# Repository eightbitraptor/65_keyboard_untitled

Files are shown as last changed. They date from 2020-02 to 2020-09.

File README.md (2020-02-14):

# 65_keyboard_untitled

My as yet unnamed 65% keyboard design

## Project structure

- [`layouts`](layouts/) - contains all the layout options I explored and the related artifacts. Generated using [Keyboard Layout Editor](https://www.keyboard-layout-editor.com)

## Layout

**tl;dr - pretty standard 65% layout WKL bottom row and split backspace**

This keyboard is a 65% board. Which means it's basically a 60% layout that's been extended by 1 column which allows us to comfortably incorporate an arrow cluster and a couple of the useful navigation keys. It's a fixed layout because it's being built just for me as a personal project. So don't expect any allowances in plate or case design for other layouts.

It's using a HHKB style layout (ANSI base with split backspace, Esc next to the 1), a Winkeyless style bottom row with a 7u spacebar, and a 1u logo blocker in the top right (because aesthetics). The right shift has been shrunk to 1.75u to allow for the up arrow. It looks like this:

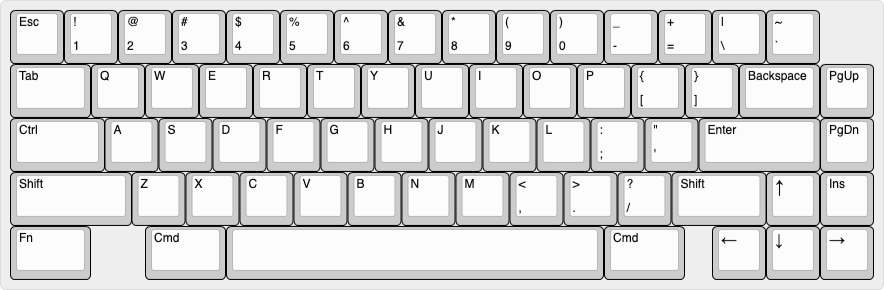
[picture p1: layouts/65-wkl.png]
65% WKL Layout


## Process

1. Decide on your layout using KLE. don't forget to either download the JSON or save your layout to Github. NOTE: To make the process easier later. I'm using the Tsangan layout to generate the platefile dxf. Tsangan is the same as WKL but with a 1u key instead of a blocker on the left side modifiers. I'm generating it this way as it makes the top case easier to design as it gives me the markings for the key that I can use as anchors in my cad program to situate the blocker.
2. copy the raw data from KLE into Swillkb. Choose cutout type and stab type - I chose simple square switch cutouts and combined cherry/co-star stab cutouts - I'm going to make the stab cutouts bigger later anyway as I want to use PCB mounted stabs.
3. Get Fusion 360 and follow along Quantriks case video, it's really good. I think I probably re-did my case 2 or three times as I understood more about Fusion in each step of the process. Also modify the design. I made the bottom/weight different as I didn't like the design in the video that much and I changed up the screw positioning and plate mounting stuff a bit. NOTE: There's no USB cutout at this point, I haven't decided where I want it yet, and there's no PCB
4. Design a PCB Schematic in KiCad. I followed along with MrKeebs videos and cross references against avrforums and some other places on the internet to verify my design. Some caveats
  - I'm using ai03's keyboard switch symbol and footprint library. I really wanted to just use the built in KiCad footprints but they don't come with a 7u spacebar, which mine is (and also has flipped stabilizers)
  - I chose the matrix layout based on the connection diagram from the kbfirmwarebuilder. I don't really know how to design a matrix other than to keep the connections as short as possible, so I went with the path of least resistance (badum tish)

## Obligatory Potato Renders

My Thinkpad struggled hard with these...

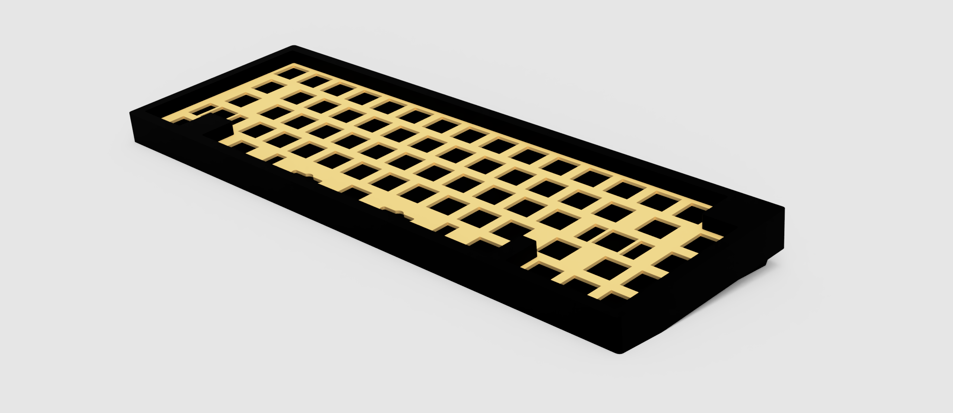
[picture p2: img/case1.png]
case 1

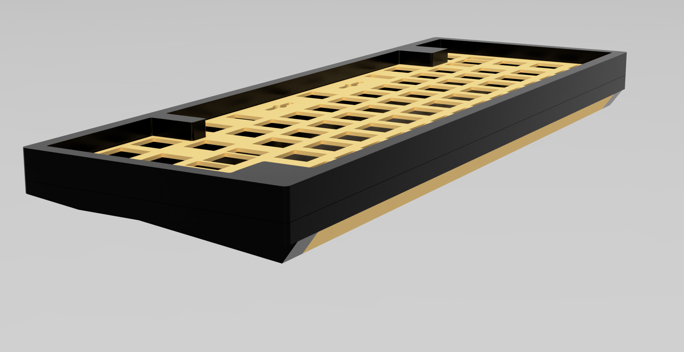
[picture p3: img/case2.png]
case 2


## KBFirmware Matrix map

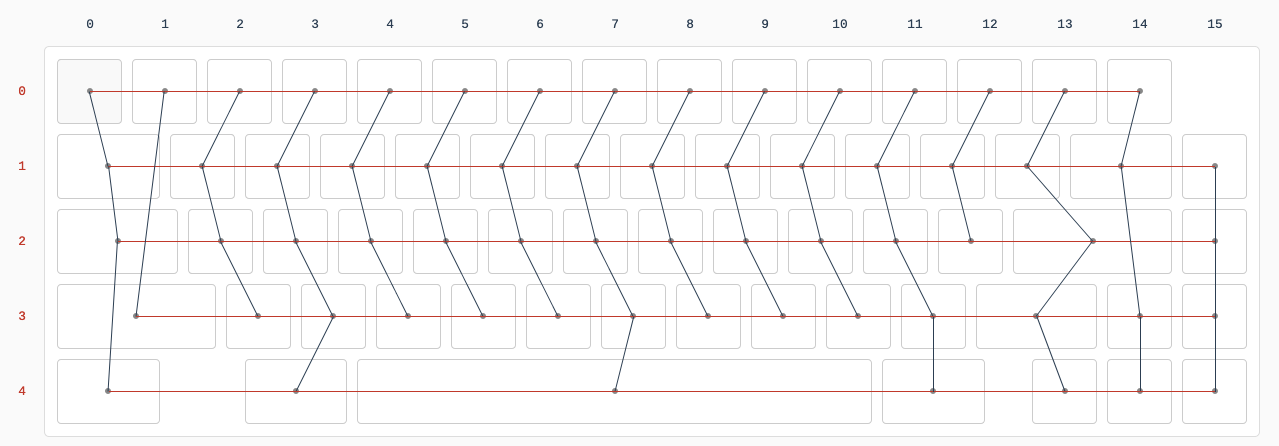
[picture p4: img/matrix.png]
wiremap


## Resources

### Videos/reading material

- Quantrik's 65% Keyboad Case design with Fusion 360 stream
  -  https://www.youtube.com/watch?v=4P0zfLLblOw
- Mr Keebs and Gondolindri's PCB design stream series
  - https://www.youtube.com/watch?v=Nk0egpDFqRA
  - https://www.youtube.com/watch?v=beyh0__tf5M
  - https://www.youtube.com/watch?v=pllksuZwJL0

### Tools

- Keyboard Layout Editor
  - http://www.keyboard-layout-editor.com/
- Swillkb's Plate CAD builder
  - http://builder.swillkb.com/
- MrKeebs PCB Layout Creator
  - http://kbpcb.mrkeebs.com/
- Keyboard Firmware Builder
  - https://kbfirmware.com

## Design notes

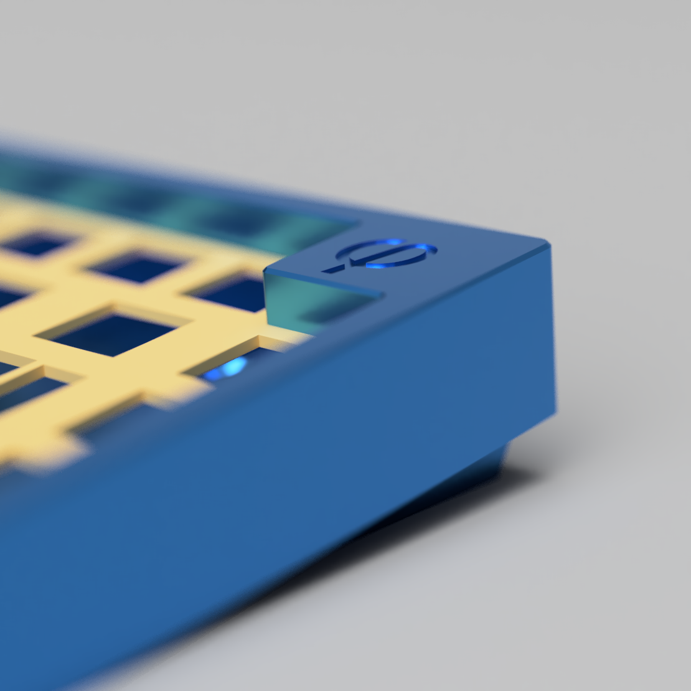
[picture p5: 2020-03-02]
Renders/design_2020-Feb-27_09-39-12AM-000_CustomizedView2532959662.png

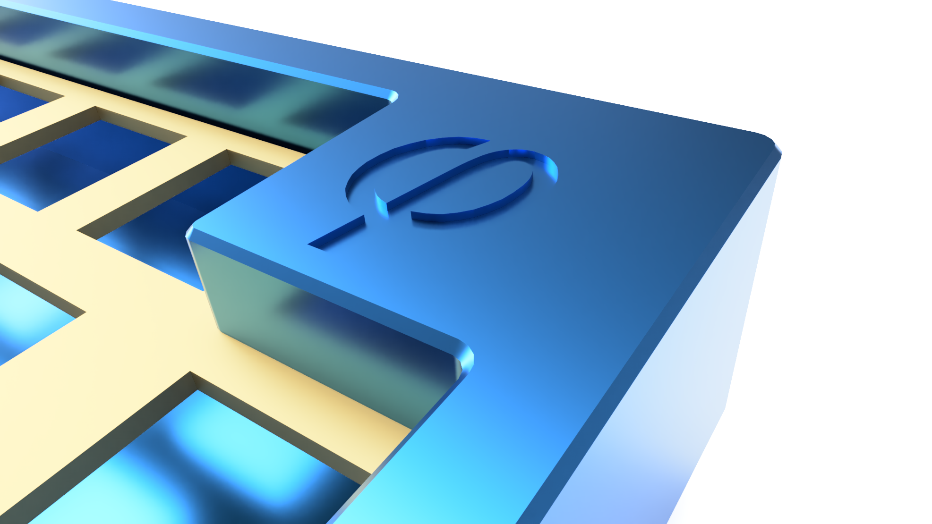
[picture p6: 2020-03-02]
Renders/design_2020-Feb-27_09-46-24AM-000_CustomizedView17708917623.png

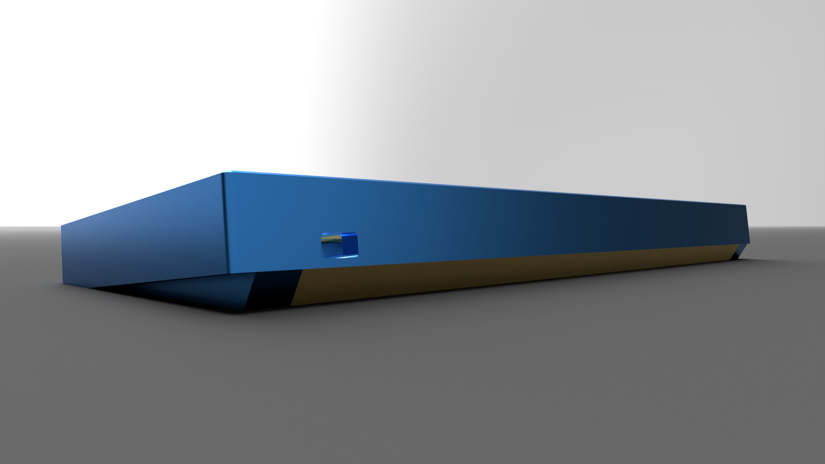
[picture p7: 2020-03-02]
Renders/design_2020-Feb-27_09-48-49AM-000_CustomizedView24021075067.png

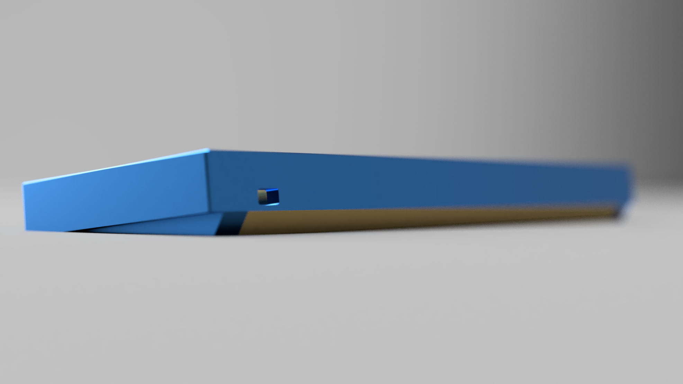
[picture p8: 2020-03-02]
Renders/design_2020-Feb-27_09-40-59AM-000_CustomizedView21154432253.png

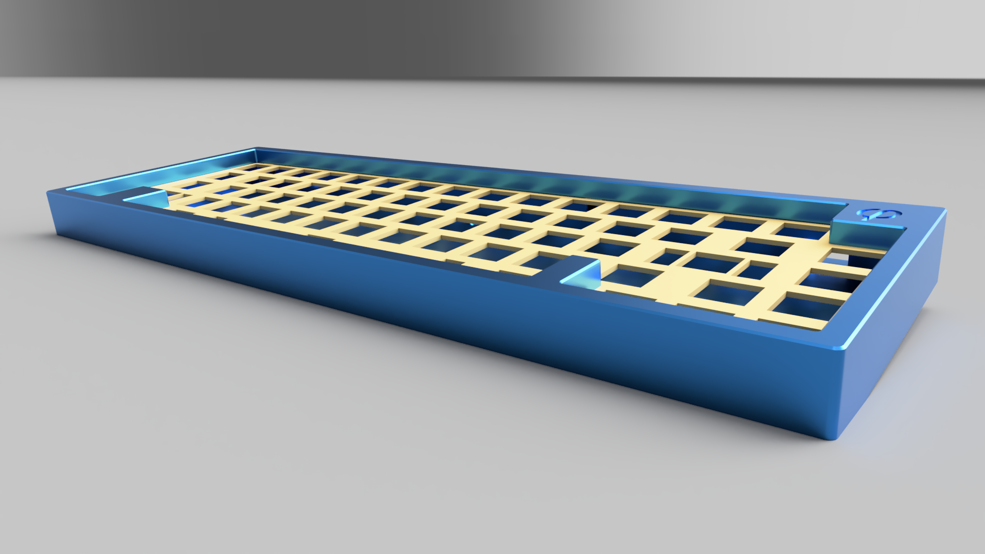
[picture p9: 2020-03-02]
Renders/design_2020-Feb-27_10-05-17AM-000_CustomizedView8284337011.png

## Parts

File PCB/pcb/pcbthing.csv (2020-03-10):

Reference | Quantity | Value | Footprint | Datasheet
C1 C8 | 2 | 1u | Capacitor_SMD:C_0805_2012Metric_Pad1.15x1.40mm_HandSolder | ~
C2 C3 C4 C5 C9 | 5 | 100n | Capacitor_SMD:C_0805_2012Metric_Pad1.15x1.40mm_HandSolder | ~
C7 C6 | 2 | 22p | Capacitor_SMD:C_0805_2012Metric_Pad1.15x1.40mm_HandSolder | ~
D1 D2 D3 D4 D5 D6 D7 D8 D9 D10 D11 D12 D13 D14 D16 D15 D17 D18 D19 D20 D21 D22 D23 D24 D25 D26 D27 D28 D29 D31 D44 D32 D33 D34 D35 D36 D37 D38 D39 D40 D41 D42 D43 D45 D58 D46 D47 D48 D49 D50 D51 D52 D53 D54 D55 D56 D57 D59 D60 D61 D62 D63 D64 D30 D65 | 65 | 1N4148W | Diode_SMD:D_SOD-123 | ~
J1 | 1 | USB_B_Micro | Connector_USB:USB_Micro-B_GCT_USB3076-30-A | ~
J2 | 1 | ICSP | Connector_PinHeader_2.54mm:PinHeader_2x03_P2.54mm_Vertical | ~
JP1 | 1 | RESET | Connector_PinSocket_2.54mm:PinSocket_1x02_P2.54mm_Vertical | ~
MX1 | 1 | ESC | MX_Only:MXOnly-1U-NoLED
MX10 | 1 | 9 | MX_Only:MXOnly-1U-NoLED
MX11 | 1 | 0 | MX_Only:MXOnly-1U-NoLED
MX12 | 1 | MINUS | MX_Only:MXOnly-1U-NoLED
MX13 | 1 | PLUS | MX_Only:MXOnly-1U-NoLED
MX14 | 1 | BSLASH | MX_Only:MXOnly-1U-NoLED
MX15 | 1 | GRAVE | MX_Only:MXOnly-1U-NoLED
MX16 | 1 | TAB_1.5 | MX_Only:MXOnly-1.5U-NoLED
MX17 | 1 | Q | MX_Only:MXOnly-1U-NoLED
MX18 | 1 | W | MX_Only:MXOnly-1U-NoLED
MX19 | 1 | E | MX_Only:MXOnly-1U-NoLED
MX2 | 1 | 1 | MX_Only:MXOnly-1U-NoLED
MX20 | 1 | R | MX_Only:MXOnly-1U-NoLED
MX21 | 1 | T | MX_Only:MXOnly-1U-NoLED
MX22 | 1 | Y | MX_Only:MXOnly-1U-NoLED
MX23 | 1 | U | MX_Only:MXOnly-1U-NoLED
MX24 | 1 | I | MX_Only:MXOnly-1U-NoLED
MX25 | 1 | O | MX_Only:MXOnly-1U-NoLED
MX26 | 1 | P | MX_Only:MXOnly-1U-NoLED
MX27 | 1 | LBRACE | MX_Only:MXOnly-1U-NoLED
MX28 | 1 | RBRACE | MX_Only:MXOnly-1U-NoLED
MX29 | 1 | BSPACE_1.5 | MX_Only:MXOnly-1.5U-NoLED
MX3 | 1 | 2 | MX_Only:MXOnly-1U-NoLED
MX30 | 1 | PGUP | MX_Only:MXOnly-1U-NoLED
MX31 | 1 | LCTRL_1.75 | MX_Only:MXOnly-1.75U-NoLED
MX32 | 1 | A | MX_Only:MXOnly-1U-NoLED
MX33 | 1 | S | MX_Only:MXOnly-1U-NoLED
MX34 | 1 | D | MX_Only:MXOnly-1U-NoLED
MX35 | 1 | F | MX_Only:MXOnly-1U-NoLED
MX36 | 1 | G | MX_Only:MXOnly-1U-NoLED
MX37 | 1 | H | MX_Only:MXOnly-1U-NoLED
MX38 | 1 | J | MX_Only:MXOnly-1U-NoLED
MX39 | 1 | K | MX_Only:MXOnly-1U-NoLED
MX4 | 1 | 3 | MX_Only:MXOnly-1U-NoLED
MX40 | 1 | L | MX_Only:MXOnly-1U-NoLED
MX41 | 1 | COLON | MX_Only:MXOnly-1U-NoLED
MX42 | 1 | QUOTE | MX_Only:MXOnly-1U-NoLED
MX43 | 1 | ENTER_2.25 | MX_Only:MXOnly-2.25U-NoLED
MX44 | 1 | PGDN | MX_Only:MXOnly-1U-NoLED
MX45 | 1 | LSHIFT_2.25 | MX_Only:MXOnly-2.25U-NoLED
MX46 | 1 | Z | MX_Only:MXOnly-1U-NoLED
MX47 | 1 | X | MX_Only:MXOnly-1U-NoLED
MX48 | 1 | C | MX_Only:MXOnly-1U-NoLED
MX49 | 1 | V | MX_Only:MXOnly-1U-NoLED
MX5 | 1 | 4 | MX_Only:MXOnly-1U-NoLED
MX50 | 1 | B | MX_Only:MXOnly-1U-NoLED
MX51 | 1 | N | MX_Only:MXOnly-1U-NoLED
MX52 | 1 | M | MX_Only:MXOnly-1U-NoLED
MX53 | 1 | LANGLE | MX_Only:MXOnly-1U-NoLED
MX54 | 1 | RANGLE | MX_Only:MXOnly-1U-NoLED
MX55 | 1 | SLASH | MX_Only:MXOnly-1U-NoLED
MX56 | 1 | RSHIFT_1.75 | MX_Only:MXOnly-1.75U-NoLED
MX57 | 1 | ARR_UP | MX_Only:MXOnly-1U-NoLED
MX58 | 1 | INS | MX_Only:MXOnly-1U-NoLED
MX59 | 1 | LALT_1.5 | MX_Only:MXOnly-1.5U-NoLED
MX6 | 1 | 5 | MX_Only:MXOnly-1U-NoLED
MX60 | 1 | LWIN_1.5 | MX_Only:MXOnly-1.5U-NoLED
MX61 | 1 | SPACE_7flipped | MX_Only:MXOnly-7U-ReversedStabilizers-NoLED
MX62 | 1 | RWIN_1.5 | MX_Only:MXOnly-1.5U-NoLED
MX63 | 1 | ARR_LT | MX_Only:MXOnly-1U-NoLED
MX64 | 1 | ARR_DN | MX_Only:MXOnly-1U-NoLED
MX65 | 1 | ARR_RT | MX_Only:MXOnly-1U-NoLED
MX7 | 1 | 6 | MX_Only:MXOnly-1U-NoLED
MX8 | 1 | 7 | MX_Only:MXOnly-1U-NoLED
MX9 | 1 | 8 | MX_Only:MXOnly-1U-NoLED
R1 | 1 | 1k | Resistor_SMD:R_1206_3216Metric_Pad1.42x1.75mm_HandSolder | ~
R2 R3 | 2 | 22 | Resistor_SMD:R_1206_3216Metric_Pad1.42x1.75mm_HandSolder | ~
R4 | 1 | 10k | Resistor_SMD:R_1206_3216Metric_Pad1.42x1.75mm_HandSolder | ~
R5 | 1 | 330 | Resistor_SMD:R_1206_3216Metric_Pad1.42x1.75mm_HandSolder | ~
U1 | 1 | ATmega32U4-AU | Package_QFP:TQFP-44_10x10mm_P0.8mm | http://ww1.microchip.com/downloads/en/DeviceDoc/Atmel-7766-8-bit-AVR-ATmega16U4-32U4_Datasheet.pdf
U2 | 1 | USBLC6-2SC6 | Package_TO_SOT_SMD:SOT-23-6 | http://www2.st.com/resource/en/datasheet/CD00050750.pdf
Y1 | 1 | 16MHz | Crystal:Crystal_SMD_5032-4Pin_5.0x3.2mm | ~

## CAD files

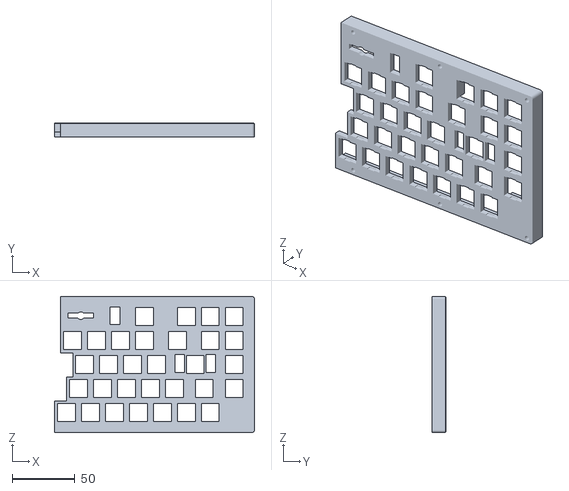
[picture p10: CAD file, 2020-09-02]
case_print_files/3d_printed_design/Top - Right.stl
158.8 x 11.0 x 108.1

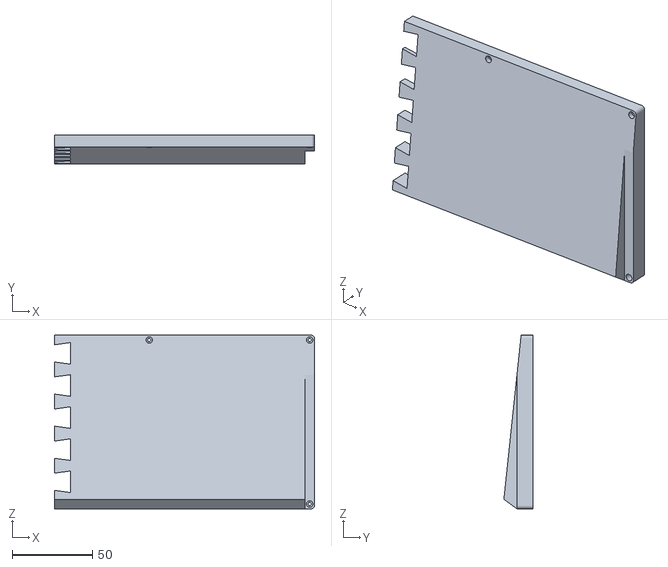
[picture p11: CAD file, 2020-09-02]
case_print_files/cnc_adapted_design/Bottom - Right.stl
162.0 x 18.3 x 108.2

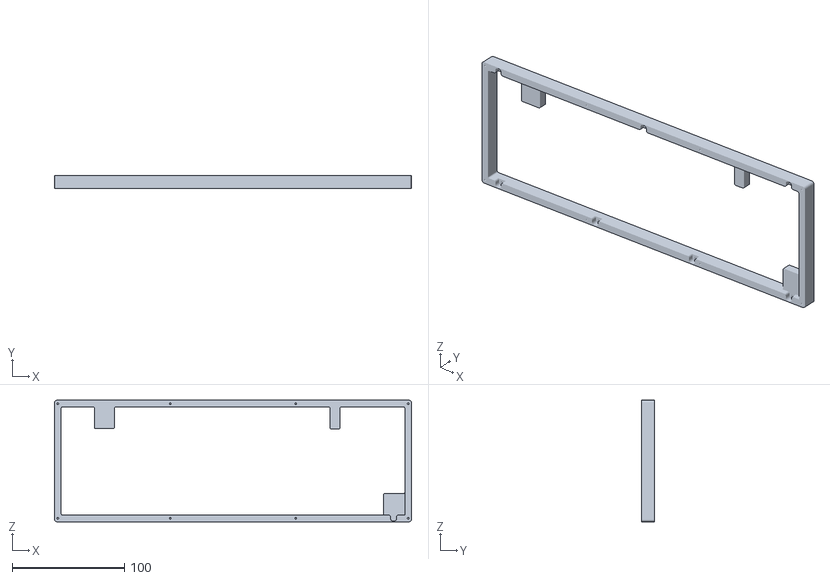
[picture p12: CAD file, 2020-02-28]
case_print_files/Top.stl
317.7 x 11.5 x 108.2

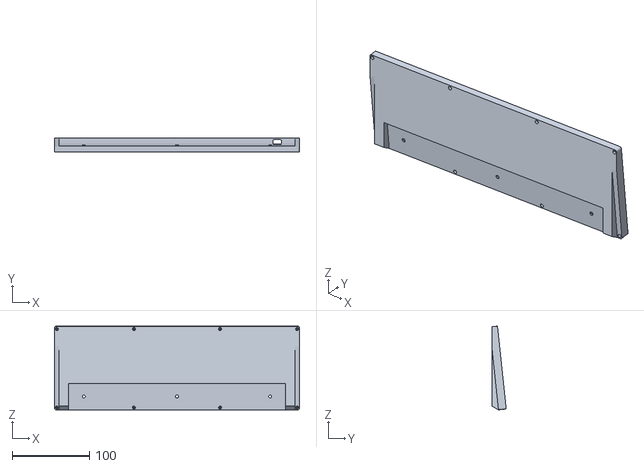
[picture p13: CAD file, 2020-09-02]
cnc/stl/Bottom.stl
317.7 x 18.8 x 108.7

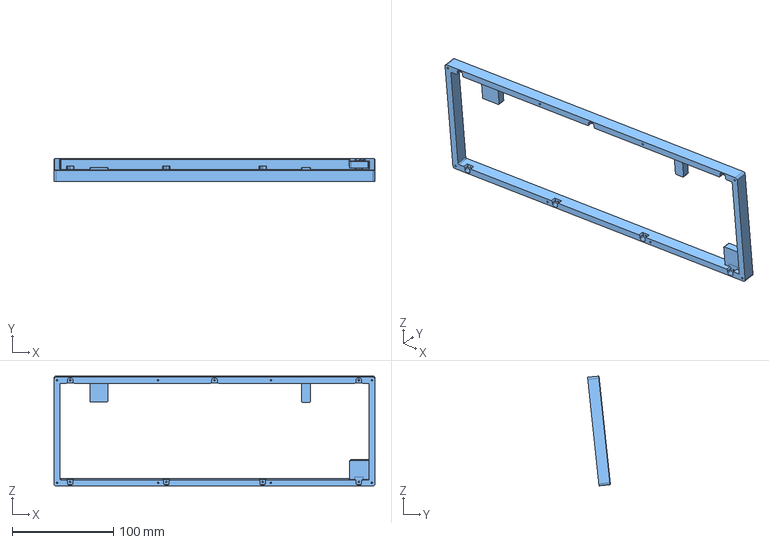
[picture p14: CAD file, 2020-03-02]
cnc/top.step
317.7 x 22.7 x 108.8 mm

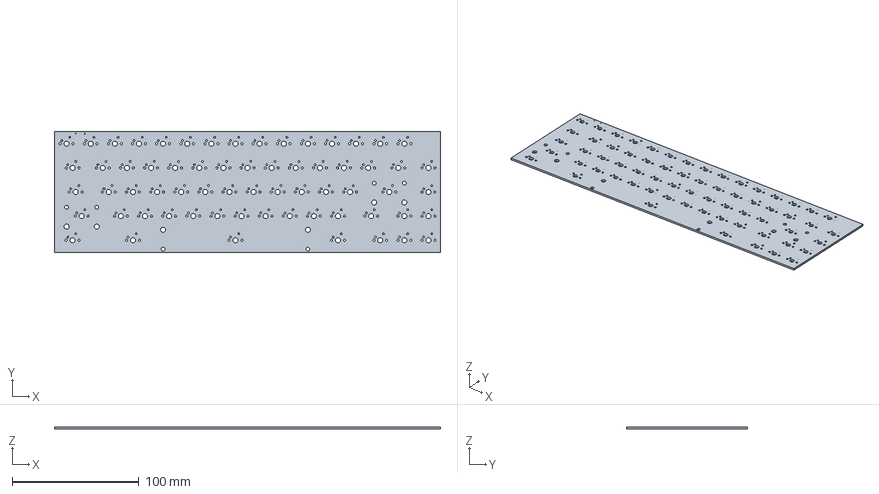
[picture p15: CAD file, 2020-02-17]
PCB/pcb/pcb.step
304.8 x 95.2 x 1.60 mm

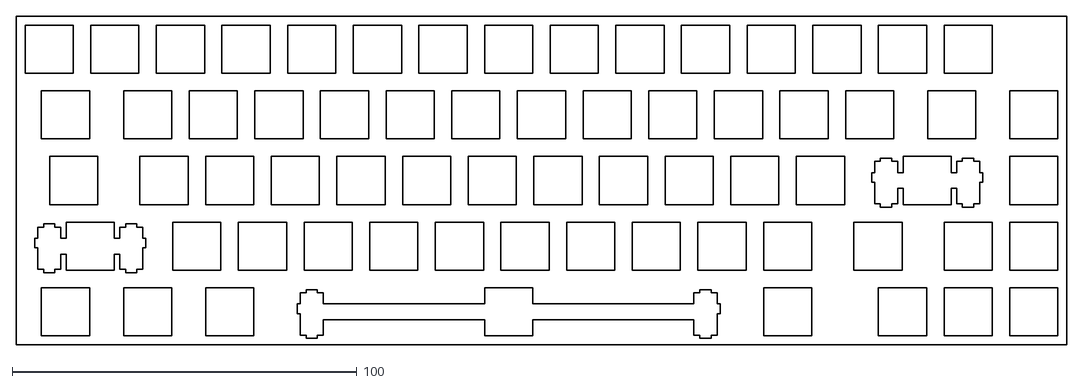
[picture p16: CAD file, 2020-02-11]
plate_2d/swillkb.dxf
304.8 x 95.2

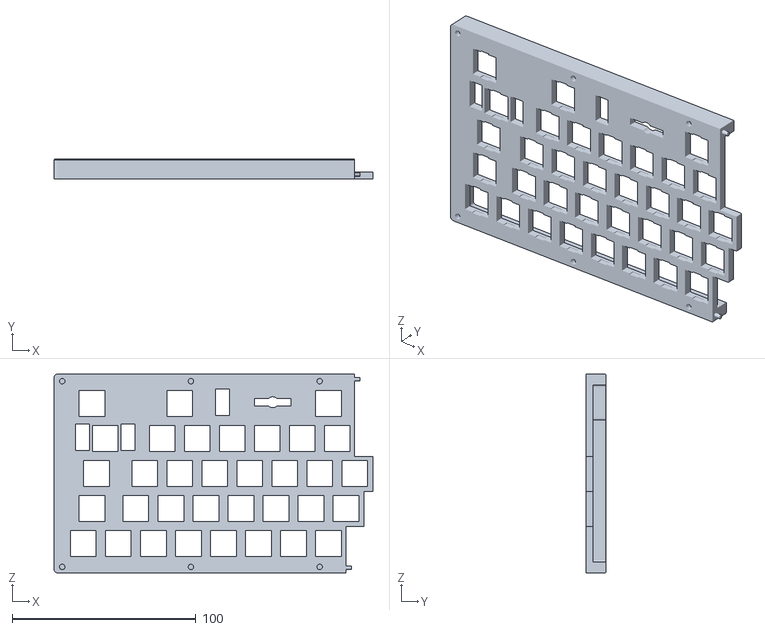
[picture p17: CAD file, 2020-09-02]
case_print_files/3d_printed_design/Top - Left.stl
173.5 x 11.0 x 108.1

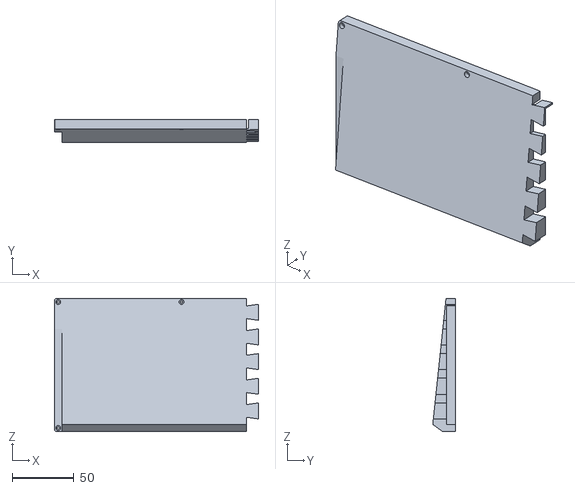
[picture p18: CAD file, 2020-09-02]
case_print_files/cnc_adapted_design/Bottom - Left.stl
165.4 x 18.3 x 108.2

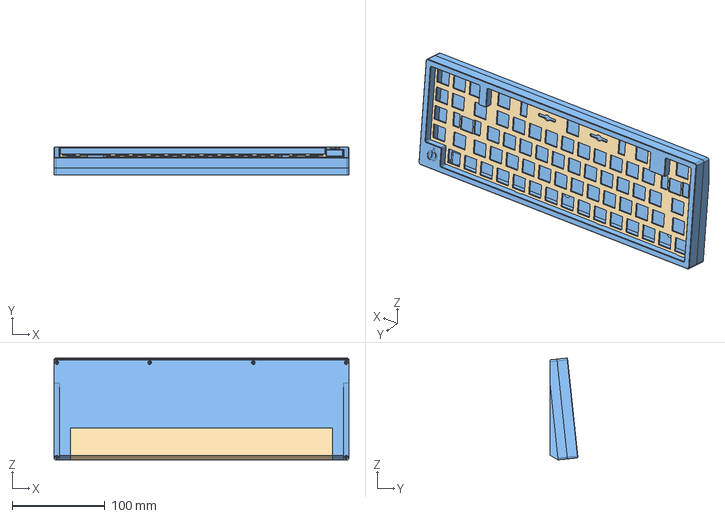
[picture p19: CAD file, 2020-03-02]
cnc/design v48.step
317.7 x 30.2 x 109.8 mm

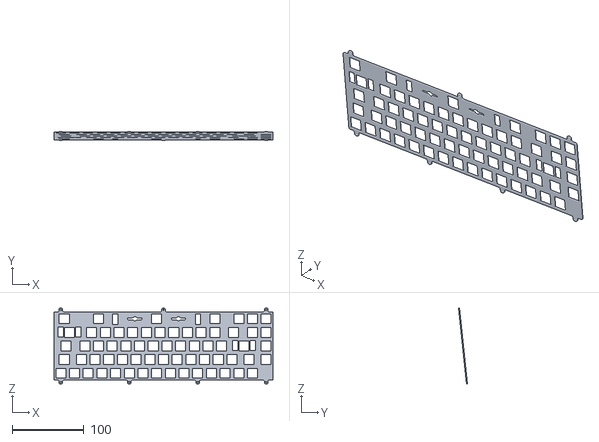
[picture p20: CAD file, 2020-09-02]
cnc/stl/Plate.stl
304.8 x 12.6 x 105.8

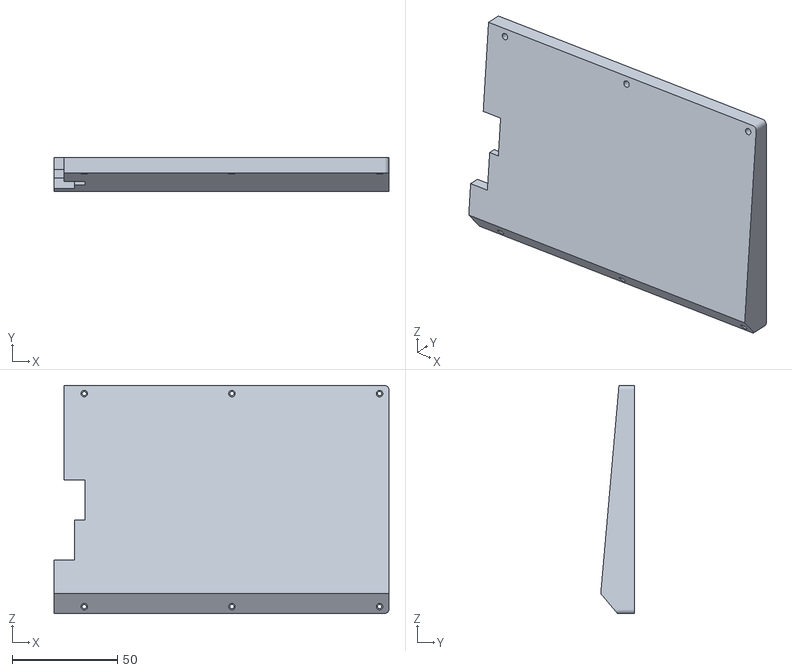
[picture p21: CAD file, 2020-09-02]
case_print_files/3d_printed_design/Bottom - Right.stl
158.8 x 15.9 x 108.1

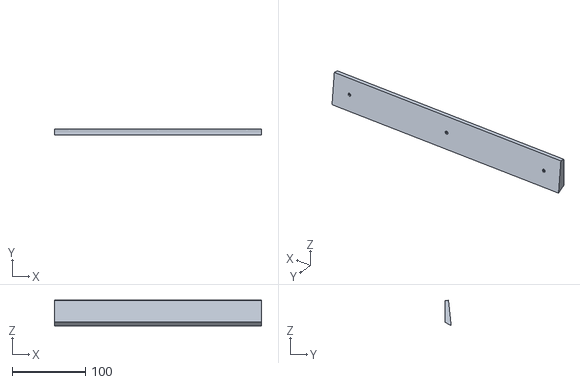
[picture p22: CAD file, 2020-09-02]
cnc/stl/Weight.stl
281.7 x 8.71 x 34.8

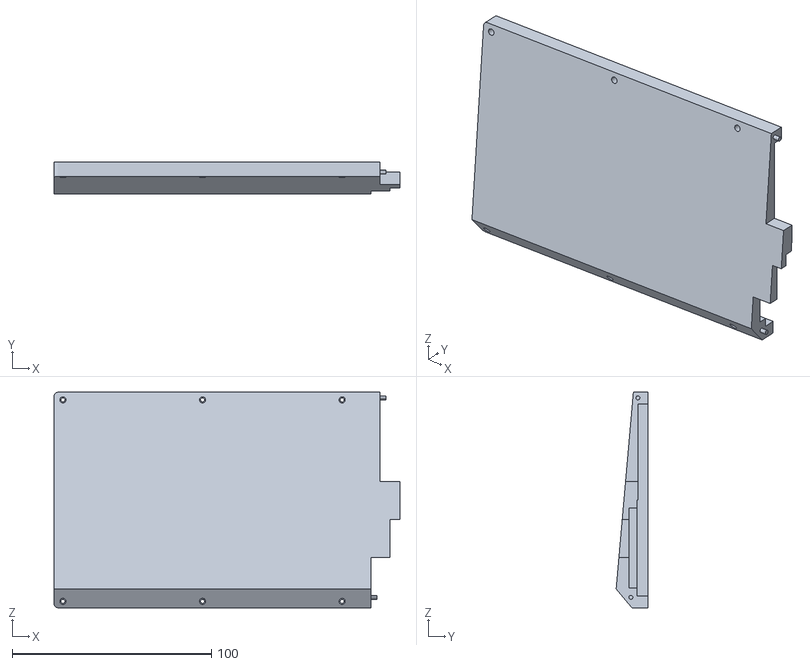
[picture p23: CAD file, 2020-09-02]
case_print_files/3d_printed_design/Bottom - Left.stl
173.5 x 15.9 x 108.1

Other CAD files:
Fusion360_files/3d_print_case.f3d
Fusion360_files/cnc_alu_case.f3z

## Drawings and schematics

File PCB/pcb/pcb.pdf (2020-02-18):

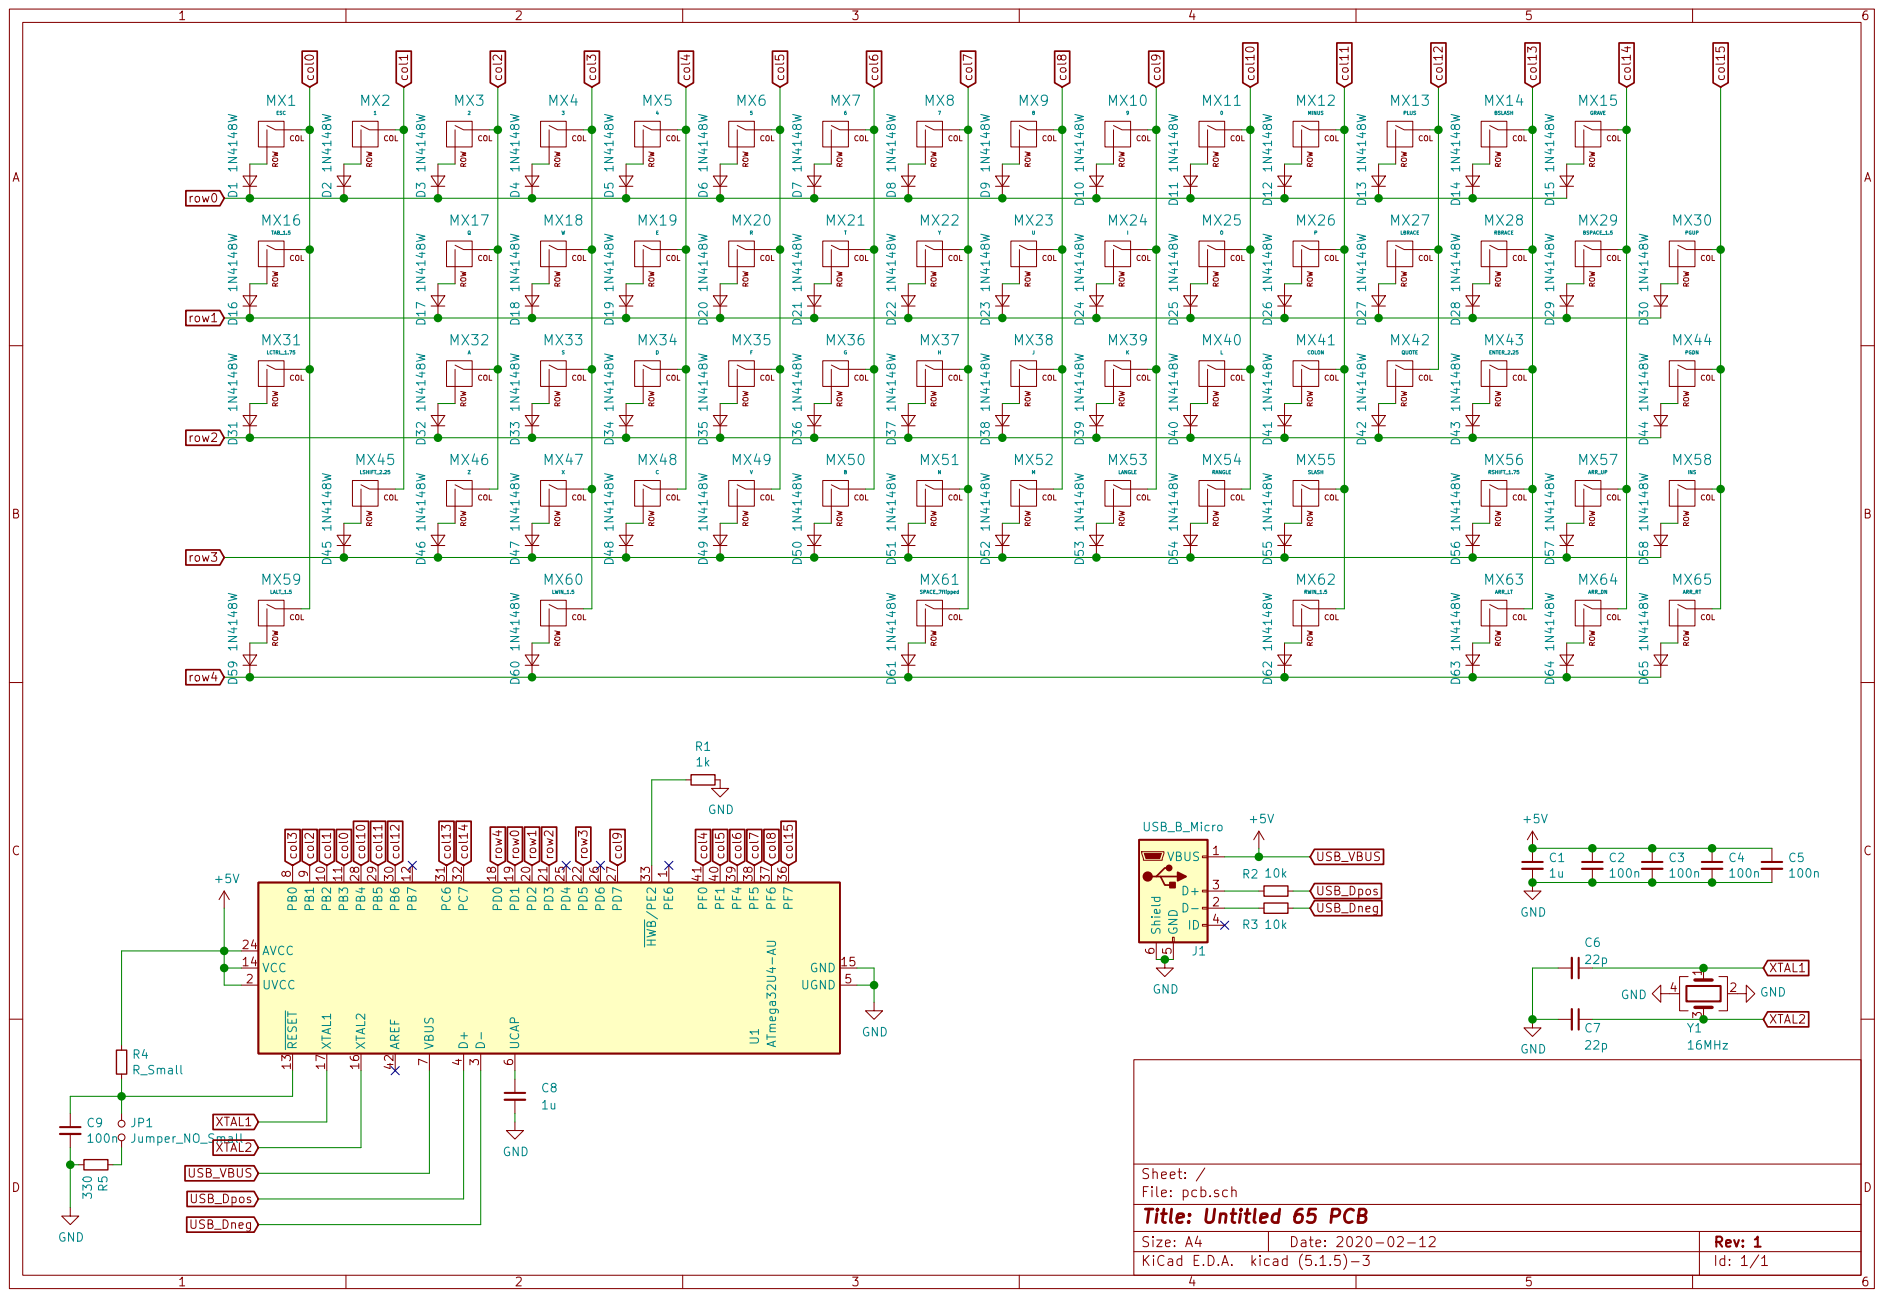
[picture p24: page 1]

1 PB2 10 PB3 11 PB7 12 RESET 13 VCC 14 GND 15 XTAL2 16 XTAL1 17 PD0 18 PD1 19 UVCC 2 PD2 20 PD3 21 PD5 22 AVCC 24 PD4 25 PD6 26 PD7 27 PB4 28 PB5 29 D- 3 PB6 30 PC6 31 PC7 32 HWB/PE2 33 PF7 36 PF6 37 PF5 38 PF4 39 D+

File: pcb.sch Sheet: /
Id: 1/1 Title: Untitled 65 PCB

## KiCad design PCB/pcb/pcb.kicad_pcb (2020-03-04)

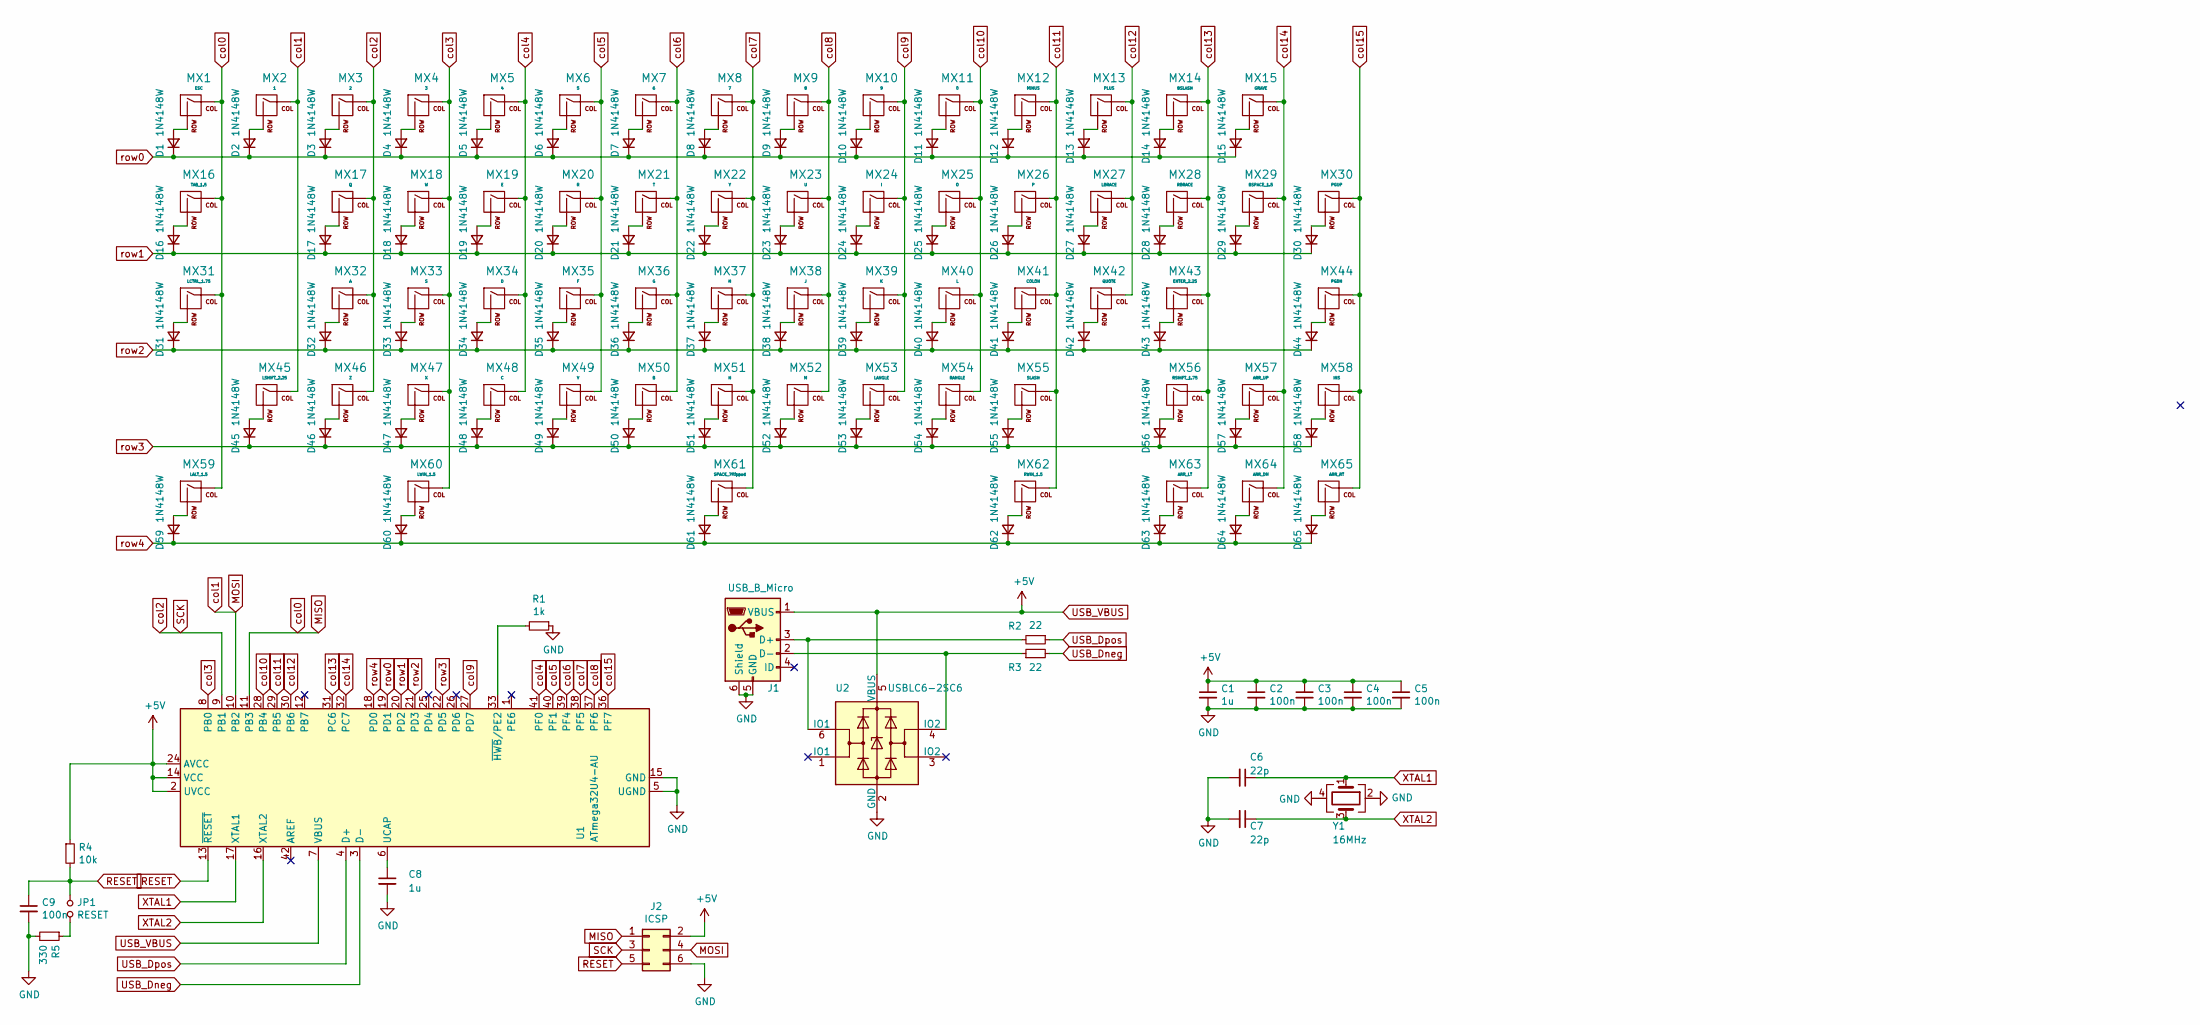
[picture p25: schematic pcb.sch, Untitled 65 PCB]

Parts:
C1, C8: 1u; C_0805_2012Metric_Pad1.15x1.40mm_HandSolder
C2, C3, C4, C5, C9: 100n; C_0805_2012Metric_Pad1.15x1.40mm_HandSolder
C6, C7: 22p; C_0805_2012Metric_Pad1.15x1.40mm_HandSolder
D1, D2, D3, D4, D5, D6, D7, D8, D9, D10, D11, D12, D13, D14, D15, D16, D17, D18, D19, D20, D21, D22, D23, D24, D25, D26, D27, D28, D29, D30, D31, D32, D33, D34, D35, D36, D37, D38, D39, D40, D41, D42, D43, D44, D45, D46, D47, D48, D49, D50, D51, D52, D53, D54, D55, D56, D57, D58, D59, D60, D61, D62, D63, D64, D65: 1N4148W; D_SOD-123
J1: USB_B_Micro; USB_Micro-B_GCT_USB3076-30-A
J2: ICSP; PinHeader_2x03_P2.54mm_Vertical
JP1: RESET; PinSocket_1x02_P2.54mm_Vertical
MX1: ESC; MXOnly-1U-NoLED
MX2: 1; MXOnly-1U-NoLED
MX3: 2; MXOnly-1U-NoLED
MX4: 3; MXOnly-1U-NoLED
MX5: 4; MXOnly-1U-NoLED
MX6: 5; MXOnly-1U-NoLED
MX7: 6; MXOnly-1U-NoLED
MX8: 7; MXOnly-1U-NoLED
MX9: 8; MXOnly-1U-NoLED
MX10: 9; MXOnly-1U-NoLED
MX11: 0; MXOnly-1U-NoLED
MX12: MINUS; MXOnly-1U-NoLED
MX13: PLUS; MXOnly-1U-NoLED
MX14: BSLASH; MXOnly-1U-NoLED
MX15: GRAVE; MXOnly-1U-NoLED
MX16: TAB_1.5; MXOnly-1.5U-NoLED
MX17: Q; MXOnly-1U-NoLED
MX18: W; MXOnly-1U-NoLED
MX19: E; MXOnly-1U-NoLED
MX20: R; MXOnly-1U-NoLED
MX21: T; MXOnly-1U-NoLED
MX22: Y; MXOnly-1U-NoLED
MX23: U; MXOnly-1U-NoLED
MX24: I; MXOnly-1U-NoLED
MX25: O; MXOnly-1U-NoLED
MX26: P; MXOnly-1U-NoLED
MX27: LBRACE; MXOnly-1U-NoLED
MX28: RBRACE; MXOnly-1U-NoLED
MX29: BSPACE_1.5; MXOnly-1.5U-NoLED
MX30: PGUP; MXOnly-1U-NoLED
MX31: LCTRL_1.75; MXOnly-1.75U-NoLED
MX32: A; MXOnly-1U-NoLED
MX33: S; MXOnly-1U-NoLED
MX34: D; MXOnly-1U-NoLED
MX35: F; MXOnly-1U-NoLED
MX36: G; MXOnly-1U-NoLED
MX37: H; MXOnly-1U-NoLED
MX38: J; MXOnly-1U-NoLED
MX39: K; MXOnly-1U-NoLED
MX40: L; MXOnly-1U-NoLED
MX41: COLON; MXOnly-1U-NoLED
MX42: QUOTE; MXOnly-1U-NoLED
MX43: ENTER_2.25; MXOnly-2.25U-NoLED
MX44: PGDN; MXOnly-1U-NoLED
MX45: LSHIFT_2.25; MXOnly-2.25U-NoLED
MX46: Z; MXOnly-1U-NoLED
MX47: X; MXOnly-1U-NoLED
MX48: C; MXOnly-1U-NoLED
MX49: V; MXOnly-1U-NoLED
MX50: B; MXOnly-1U-NoLED
MX51: N; MXOnly-1U-NoLED
MX52: M; MXOnly-1U-NoLED
MX53: LANGLE; MXOnly-1U-NoLED
MX54: RANGLE; MXOnly-1U-NoLED
MX55: SLASH; MXOnly-1U-NoLED
MX56: RSHIFT_1.75; MXOnly-1.75U-NoLED
MX57: ARR_UP; MXOnly-1U-NoLED
MX58: INS; MXOnly-1U-NoLED
MX59: LALT_1.5; MXOnly-1.5U-NoLED
MX60: LWIN_1.5; MXOnly-1.5U-NoLED
MX61: SPACE_7flipped; MXOnly-7U-ReversedStabilizers-NoLED
MX62: RWIN_1.5; MXOnly-1.5U-NoLED
MX63: ARR_LT; MXOnly-1U-NoLED
MX64: ARR_DN; MXOnly-1U-NoLED
MX65: ARR_RT; MXOnly-1U-NoLED
R1: 1k; R_1206_3216Metric_Pad1.42x1.75mm_HandSolder
R2, R3: 22; R_1206_3216Metric_Pad1.42x1.75mm_HandSolder
R4: 10k; R_1206_3216Metric_Pad1.42x1.75mm_HandSolder
R5: 330; R_1206_3216Metric_Pad1.42x1.75mm_HandSolder
U1: ATmega32U4-AU; TQFP-44_10x10mm_P0.8mm
U2: USBLC6-2SC6; SOT-23-6
Y1: 16MHz; Crystal_SMD_5032-4Pin_5.0x3.2mm

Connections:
GND: C1.2, C2.2, C3.2, C4.2, C5.2, C6.2, C7.2, C8.2, C9.2, J1.5 (GND), J1.6 (Shield), J2.6, R1.1, R5.2, U1.5 (UGND), U1.15 (GND), U1.23 (GND), U1.35 (GND), U1.43 (GND), U2.2 (GND), Y1.2, Y1.4
MISO: J2.1, MX1.1 (COL), MX16.1 (COL), MX31.1 (COL), MX59.1 (COL), U1.11 (PB3)
MOSI: J2.4, MX2.1 (COL), MX45.1 (COL), U1.10 (PB2)
unnamed: C8.1, U1.6 (UCAP)
unnamed: D1.2 (A), MX1.2 (ROW)
unnamed: D2.2 (A), MX2.2 (ROW)
unnamed: D3.2 (A), MX3.2 (ROW)
unnamed: D4.2 (A), MX4.2 (ROW)
unnamed: D5.2 (A), MX5.2 (ROW)
unnamed: D6.2 (A), MX6.2 (ROW)
unnamed: D7.2 (A), MX7.2 (ROW)
unnamed: D8.2 (A), MX8.2 (ROW)
unnamed: D9.2 (A), MX9.2 (ROW)
unnamed: D10.2 (A), MX10.2 (ROW)
unnamed: D11.2 (A), MX11.2 (ROW)
unnamed: D12.2 (A), MX12.2 (ROW)
unnamed: D13.2 (A), MX13.2 (ROW)
unnamed: D14.2 (A), MX14.2 (ROW)
unnamed: D15.2 (A), MX15.2 (ROW)
unnamed: D16.2 (A), MX16.2 (ROW)
unnamed: D17.2 (A), MX17.2 (ROW)
unnamed: D18.2 (A), MX18.2 (ROW)
unnamed: D19.2 (A), MX19.2 (ROW)
unnamed: D20.2 (A), MX20.2 (ROW)
unnamed: D21.2 (A), MX21.2 (ROW)
unnamed: D22.2 (A), MX22.2 (ROW)
unnamed: D23.2 (A), MX23.2 (ROW)
unnamed: D24.2 (A), MX24.2 (ROW)
unnamed: D25.2 (A), MX25.2 (ROW)
unnamed: D26.2 (A), MX26.2 (ROW)
unnamed: D27.2 (A), MX27.2 (ROW)
unnamed: D28.2 (A), MX28.2 (ROW)
unnamed: D29.2 (A), MX29.2 (ROW)
unnamed: D30.2 (A), MX30.2 (ROW)
unnamed: D31.2 (A), MX31.2 (ROW)
unnamed: D32.2 (A), MX32.2 (ROW)
unnamed: D33.2 (A), MX33.2 (ROW)
unnamed: D34.2 (A), MX34.2 (ROW)
unnamed: D35.2 (A), MX35.2 (ROW)
unnamed: D36.2 (A), MX36.2 (ROW)
unnamed: D37.2 (A), MX37.2 (ROW)
unnamed: D38.2 (A), MX38.2 (ROW)
unnamed: D39.2 (A), MX39.2 (ROW)
unnamed: D40.2 (A), MX40.2 (ROW)
unnamed: D41.2 (A), MX41.2 (ROW)
unnamed: D42.2 (A), MX42.2 (ROW)
unnamed: D43.2 (A), MX43.2 (ROW)
unnamed: D44.2 (A), MX44.2 (ROW)
unnamed: D45.2 (A), MX45.2 (ROW)
unnamed: D46.2 (A), MX46.2 (ROW)
unnamed: D47.2 (A), MX47.2 (ROW)
unnamed: D48.2 (A), MX48.2 (ROW)
unnamed: D49.2 (A), MX49.2 (ROW)
unnamed: D50.2 (A), MX50.2 (ROW)
unnamed: D51.2 (A), MX51.2 (ROW)
unnamed: D52.2 (A), MX52.2 (ROW)
unnamed: D53.2 (A), MX53.2 (ROW)
unnamed: D54.2 (A), MX54.2 (ROW)
unnamed: D55.2 (A), MX55.2 (ROW)
unnamed: D56.2 (A), MX56.2 (ROW)
unnamed: D57.2 (A), MX57.2 (ROW)
unnamed: D58.2 (A), MX58.2 (ROW)
unnamed: D59.2 (A), MX59.2 (ROW)
unnamed: D60.2 (A), MX60.2 (ROW)
unnamed: D61.2 (A), MX61.2 (ROW)
unnamed: D62.2 (A), MX62.2 (ROW)
unnamed: D63.2 (A), MX63.2 (ROW)
unnamed: D64.2 (A), MX64.2 (ROW)
unnamed: D65.2 (A), MX65.2 (ROW)
unnamed: J1.2 (D-), R3.1, U2.4 (IO2)
unnamed: J1.3 (D+), R2.2, U2.6 (IO1)
unnamed: JP1.2, R5.1
unnamed: R1.2, U1.33 (~HWB~/PE2)
RESET: C9.1, J2.5, JP1.1, R4.2, U1.13 (~RESET)
SCK: J2.3, MX3.1 (COL), MX17.1 (COL), MX32.1 (COL), MX46.1 (COL), U1.9 (PB1)
USB_Dneg: R3.2, U1.3 (D-)
USB_Dpos: R2.1, U1.4 (D+)
USB_VBUS: C1.1, C2.1, C3.1, C4.1, C5.1, J1.1 (VBUS), J2.2, R4.1, U1.2 (UVCC), U1.7 (VBUS), U1.14 (VCC), U1.24 (AVCC), U1.34 (VCC), U1.44 (AVCC), U2.5 (VBUS)
XTAL1: C6.1, U1.17 (XTAL1), Y1.1
XTAL2: C7.1, U1.16 (XTAL2), Y1.3
col3: MX4.1 (COL), MX18.1 (COL), MX33.1 (COL), MX47.1 (COL), MX60.1 (COL), U1.8 (PB0)
col4: MX5.1 (COL), MX19.1 (COL), MX34.1 (COL), MX48.1 (COL), U1.41 (PF0)
col5: MX6.1 (COL), MX20.1 (COL), MX35.1 (COL), MX49.1 (COL), U1.40 (PF1)
col6: MX7.1 (COL), MX21.1 (COL), MX36.1 (COL), MX50.1 (COL), U1.39 (PF4)
col7: MX8.1 (COL), MX22.1 (COL), MX37.1 (COL), MX51.1 (COL), MX61.1 (COL), U1.38 (PF5)
col8: MX9.1 (COL), MX23.1 (COL), MX38.1 (COL), MX52.1 (COL), U1.37 (PF6)
col9: MX10.1 (COL), MX24.1 (COL), MX39.1 (COL), MX53.1 (COL), U1.27 (PD7)
col10: MX11.1 (COL), MX25.1 (COL), MX40.1 (COL), MX54.1 (COL), U1.28 (PB4)
col11: MX12.1 (COL), MX26.1 (COL), MX41.1 (COL), MX55.1 (COL), MX62.1 (COL), U1.29 (PB5)
col12: MX13.1 (COL), MX27.1 (COL), MX42.1 (COL), U1.30 (PB6)
col13: MX14.1 (COL), MX28.1 (COL), MX43.1 (COL), MX56.1 (COL), MX63.1 (COL), U1.31 (PC6)
col14: MX15.1 (COL), MX29.1 (COL), MX57.1 (COL), MX64.1 (COL), U1.32 (PC7)
col15: MX30.1 (COL), MX44.1 (COL), MX58.1 (COL), MX65.1 (COL), U1.36 (PF7)
row0: D1.1 (K), D2.1 (K), D3.1 (K), D4.1 (K), D5.1 (K), D6.1 (K), D7.1 (K), D8.1 (K), D9.1 (K), D10.1 (K), D11.1 (K), D12.1 (K), D13.1 (K), D14.1 (K), D15.1 (K), U1.19 (PD1)
row1: D16.1 (K), D17.1 (K), D18.1 (K), D19.1 (K), D20.1 (K), D21.1 (K), D22.1 (K), D23.1 (K), D24.1 (K), D25.1 (K), D26.1 (K), D27.1 (K), D28.1 (K), D29.1 (K), D30.1 (K), U1.20 (PD2)
row2: D31.1 (K), D32.1 (K), D33.1 (K), D34.1 (K), D35.1 (K), D36.1 (K), D37.1 (K), D38.1 (K), D39.1 (K), D40.1 (K), D41.1 (K), D42.1 (K), D43.1 (K), D44.1 (K), U1.21 (PD3)
row3: D45.1 (K), D46.1 (K), D47.1 (K), D48.1 (K), D49.1 (K), D50.1 (K), D51.1 (K), D52.1 (K), D53.1 (K), D54.1 (K), D55.1 (K), D56.1 (K), D57.1 (K), D58.1 (K), U1.22 (PD5)
row4: D59.1 (K), D60.1 (K), D61.1 (K), D62.1 (K), D63.1 (K), D64.1 (K), D65.1 (K), U1.18 (PD0)

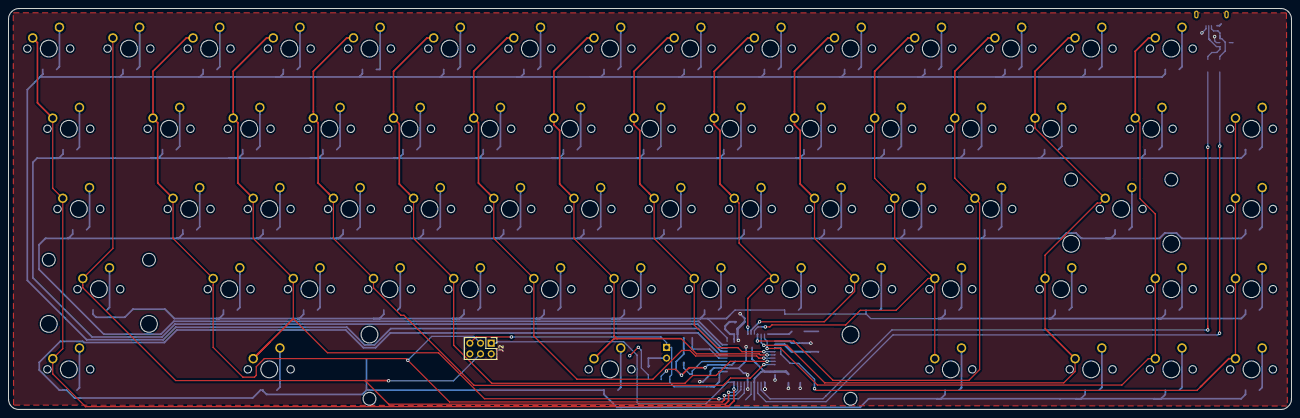
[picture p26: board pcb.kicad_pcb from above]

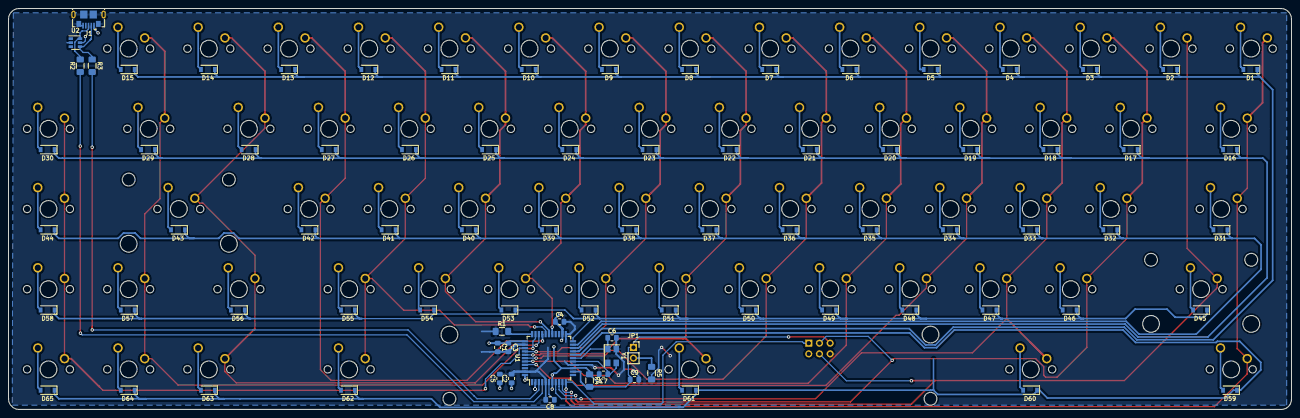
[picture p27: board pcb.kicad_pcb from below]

Board: 2 copper layers, 304.8 x 95.3 mm, 150 parts (84 on the bottom side), 98 nets.

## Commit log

2020-02-07 Generate a platefile DXF and start the process of modelling it
    This used ai03's plate generator to generate a plate from the KLE raw, I
    then imported this into Fusion so I can tweak it and build the case by
    following along with Quantrik's Youtube video.
    So far I've flipped the spacebar stab and built out the case wall.
    [plate-20200207-141923 v3.f3d, plate-20200207-141923.dxf]
2020-02-11 Swap ai03 generated plate with swillkb
    [plate-20200207-141923.dxf, swillkb.dxf]
2020-02-11 Update Fusion360 files to reflect latest changes.
    [design-backup.f3d, plate-20200207-141923 v3.f3d]
2020-02-12 Case Files complete except USB cut out
    I don't know where to put the USB Cutout yet as I have no PCB.
    Other than that I think we're done...
    [case-no_usb_cutout.f3d, design-backup.f3d]
2020-02-12 Get started on the PCB layout
    [pcb.kicad_pcb, pcb.sch]
2020-02-14 Refactor controller layout.
    Think that this is pretty much complete now.
    Next up the matrix
    [pcb.sch]
2020-02-14 Add ai03's keyboard switch lib
    KiCad has MX switches built in but nothing for a 7u spacebar :(
2020-02-14 Build the switch Matrix based on kbfirmwarebuilder
    [pcb.sch]
2020-02-14 reset annotations
    [pcb.sch]
2020-02-14 Add footprints
    [pcb.sch]
2020-02-17 Layout the switches and diodes
    [pcb.kicad_pcb, pcb.sch]
2020-02-17 Route the matrix
    [pcb.kicad_pcb]
2020-02-17 Clean up the project files
    * Move the submodule to where it should be in order to prevent KiCAD
    from creating a weird project file in the wrong directory
2020-02-17 Layout the PCB and generate Gerbers.
    I am an idiot. This is my first pass at laying out the board.
    What I should have done is mark out the edge cuts and then generate a 3d
    model to import into Fusion to check that it fits in the case.
    I did not do this until after I'd layed out the board :'( and it's about
    5mm too long on each side.
    So now I need to make the board smaller by a significant amount and redo
    the layout.
    Think I learned a lot about laying out a PCB though.
    [pcb-B_Cu.gbr, pcb-B_Mask.gbr, pcb-B_Paste.gbr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]
2020-02-17 New outline (checked with Fusion model)
    [pcb.step]
2020-02-18 Layout components around MC
    Move diodes to be differently oriented
    [pcb.kicad_pcb]
2020-02-18 Finish Layout
    [pcb.kicad_pcb, pcb.sch]
2020-02-18 Generate Gerbers and PDF
    [pcb-B_Cu.gbr, pcb-B_Mask.gbr, pcb-B_Paste.gbr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]
2020-02-24 Add and ICSP connector and change some values
    [pcb.sch]
2020-02-27 Move the USB port and regenerate the Gerbers
    [pcb-B_Cu.gbr, pcb-B_Mask.gbr, pcb-B_Paste.gbr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]
2020-02-28 add latest fusion 360 backup
    [Bottom.stl, Top.stl, Weight.stl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]
2020-03-02 Case progress and Renders
    [Bottom.stl, Plate.stl, Weight.stl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]
2020-03-02 PCB progress
    [pcb.kicad_pcb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]
2020-03-04 Add ESD Protection and make sure the fill zones are on both sides of the board
    [pcb.kicad_pcb, pcb.sch]
2020-03-04 Increase the distance between tracks/pads
    [pcb.kicad_pcb]
2020-03-04 Regenerate gerbers for manufacturing
    [pcb.kicad_pcb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]
2020-03-10 Add final Gerbers and BOM generation
    [pcb.csv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]
2020-03-11 Update Fusion 360 files
    [3d_print_case.f3d, case-no_usb_cutout.f3d, cnc_alu_case.f3z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]
2020-05-19 add the new 3d printed design files
    [Bottom - Left.stl, Bottom - Right.stl, Bottom.stl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]
2020-09-02 Update STL and some GCode from the first prototype
    [Bottom - Left.stl, Bottom - Right.stl, Bottom.stl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]
